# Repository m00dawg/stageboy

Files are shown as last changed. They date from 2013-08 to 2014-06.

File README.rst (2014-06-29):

StageBoy
========

Stage-Hardened ArduinoBoy, Balun, Noise Rejection Box all rolled into one.

Noise-Rejection Explained
-------------------------

The transformer is wired in such a way that the stereo input is wired to the
outside pins of the transformer, with the ground being the center-tap. So left
and right become inversed of each other. Thus, when they are playing the same
content, in theory, the audio would be cancelled out. This is what is being 
exploited to ultimately reject noise.

Hard panning your desired content (e.g. music), say, to the left, and leaving
the right channel with no content means that the noise that is common to both
channels ends up getting rejected by way of being inverted and then cancelled
out.

For the GameBoy, this has a noticeable improvement over the background noise,
including the high pitched whine. Any source which has common noise on both
channels can be used. Which channel is used does not matter, although typically
the left is used as this keep the musical content un-inverted.

In practice, it is not perfect and, in fact, an active circuit (using op-amps)
may further improve rejection. This would have required a much more complicated
power supply and, as a result, the passive route was preffered. It is generally
good when sticking with the recommended transformer (see BOM) or one better. 
The quality of the transformer has a direct affect on both the noise rejection
and the ultiamte quality of the audio output.

Using a transformer means that the output is balanced and isolated. Thus there 
should not be any issues with ground loops and longer audio cables can be used 
with less signal degradation. Most mixers and audio capture devices offer balanced 
inputs and it is highly recommended to use them if at all possible.

Programming the StageBoy
------------------------

Pulling the Chip
~~~~~~~~~~~~~~~~

If you don't want to mess with the ISP headers, you can likely just stuff
an AVR chip which is already Arduinofied (it has the bootlodaer already -
as in you previously flashed it with the bootloader or bought an AVR 
from a place that will flash it for you) into an Uno board and upload
the code as you normally would. Then you can pull the chip and put it into
the StageBoy.

If you're not making any changes, and are reasonably confident with your 
soldering work, this should work without issue. Using the ISP headers, 
however, makes thins easier to troubleshoot.

Using the ISP Headers
~~~~~~~~~~~~~~~~~~~~~

ISP headers have been used successful with EvilMadScientist's ISP Shield
(see http://shop.evilmadscientist.com/productsmenu/tinykitlist/253-ispshield)
and an Arduino Duemilanove. Wires are hooked up in a similar way to the
Arduino ISP how-to (see: http://arduino.cc/en/Tutorial/ArduinoISP) but
with a 6-pin ISP header on the other end. A standard ISP cable should
work, and would be a lot easier, but hasn't been tested.

With the ISP Shield, program the Arduino connect to the shield using the
ArduinoISP sketch available with the Ardunio IDE (under Examples). Then
connect the shield to the Arduino and the ISP cable to the StageBoy. Burning
the bootloader should be optional, but it has never been tested without. To
burn the bootloader, pick the Arduino board you are using as the programmer
in the Tools -> Board menu. Then set the Programmer to Arduino As ISP under
Tools -> Programmer. Then go to Tools -> Burn Bootloader.

Having done that, load up the StageBoy sketch, and then press SHIFT and click
on the upload icon. This uploads the code to the StageBoy instead of to the
Arduino board acting as the programmer.

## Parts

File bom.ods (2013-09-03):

Part | Value | Mouser Part # | Other Part #
Enclosure | .72 x 3.07 x 1.69 Extruded Enclsoure | 546-1455K1201 (https://www.mouser.com/Search/ProductDetail.aspx)
B1 | Rectifier | 625-W005G-E4
C3 | 22pF | 581-SA102A220JAR (http://www.mouser.com/Search/ProductDetail.aspx)
C4 | 22pF | 581-SA102A220JAR (http://www.mouser.com/Search/ProductDetail.aspx)
C1 | 100nF | 810-FK18X7R1E104K (http://www.mouser.com/Search/ProductDetail.aspx)
C2 | 100nF | 810-FK18X7R1E104K (http://www.mouser.com/Search/ProductDetail.aspx)
C5 | 100nF | 810-FK18X7R1E104K (http://www.mouser.com/Search/ProductDetail.aspx)
C9 | 100nF | 810-FK18X7R1E104K (http://www.mouser.com/Search/ProductDetail.aspx)
C8 | 330nF | 810-FK18X5R1E334K
C6 | 22uF | 667-EEU-HD1H220B
C7 | 2200uF | 667-EEU-HD1E222B
D1 | 1N4148 Diode | 512-1N4148 (http://www.mouser.com/ProductDetail/Fairchild-Semiconductor/1N4148/?qs=sGAEpiMZZMudZehw8RjeZWbu6z6oTQTL)
GB5V | 2-pin Jumper |  | avishowtech.com
GNDLFT | 2-pin Jumper |  | avishowtech.com
MIDI-IN | 2-pin SIL Header |  | avishowtech.com
MIDI-OUT | 3-pin SIL Header |  | avishowtech.com
5VDC | 2-pin SIL Header |  | avishowtech.com
X4 | 2-pin SIL Header |  | avishowtech.com
ISP | 2x3 DIL Header |  | avishowtech.com
R5 | 220 Ohm | 660-MF1/4CCT52R2200F (http://www.mouser.com/Search/ProductDetail.aspx)
R9 | 220 Ohm | 660-MF1/4CCT52R2200F (http://www.mouser.com/Search/ProductDetail.aspx)
R10 | 220 Ohm | 660-MF1/4CCT52R2200F (http://www.mouser.com/Search/ProductDetail.aspx)
R8 | 270 Ohm | 660-MF1/4DC2700F (http://www.mouser.com/Search/ProductDetail.aspx)
SW1 | 3-Position DIP | 611-BD03
MIDI IN | Female MIDI |  | avishowtech.com
MIDI OUT | Female MIDI |  | avishowtech.com
GBIO | Female MIDI |  | avishowtech.com
GB Connector | Male 5-pin DIN 180 Deg | 568-NYS322G (http://www.mouser.com/Search/ProductDetail.aspx?R=NYS322Gvirtualkey56810000virtualkey568-NYS322G) | <--- Untested
IC1 | AVR328 | 556-ATMEGA328P-PU (http://www.mouser.com/Search/ProductDetail.aspx)
IC1 Socket | 28-pin Narrow (.3”) | 517-4828-3004-CP (http://www.mouser.com/Search/ProductDetail.aspx)
IC2 | 7805 | 511-L7805CV (http://www.mouser.com/Search/ProductDetail.aspx?R=L7805CVvirtualkey51120000virtualkey511-L7805CV)
OK1 | 6N138 Optocoupler | 782-6N138 (http://www.mouser.com/Search/ProductDetail.aspx?R=6N138virtualkey61370000virtualkey782-6N138)
OK1 Socket | 8-pin DIP Socket | 517-4808-3000-CP (http://www.mouser.com/Search/ProductDetail.aspx)
STEREO IN | 3.5mm Audio Jack | 806-STX-31205B284C (http://www.mouser.com/Search/ProductDetail.aspx)
MONO BALANCED OUT | 1/4” TRS Jack | 550-20301 (https://www.mouser.com/Search/ProductDetail.aspx?R=NMJ6HFD2virtualkey56810000virtualkey550-20301)
J1 | 2mm/5mm DC Jack | 806-KLDX-0202-A (http://www.mouser.com/ProductDetail/Kycon/KLDX-0202-A/)
LED | 3mm LED |  | avishowtech.com
Q1 | 16MHz OSC | 695-HC49US-16-U (http://www.mouser.com/Search/ProductDetail.aspx)
XFORMER | EDCOR PCW |  | edcor.com

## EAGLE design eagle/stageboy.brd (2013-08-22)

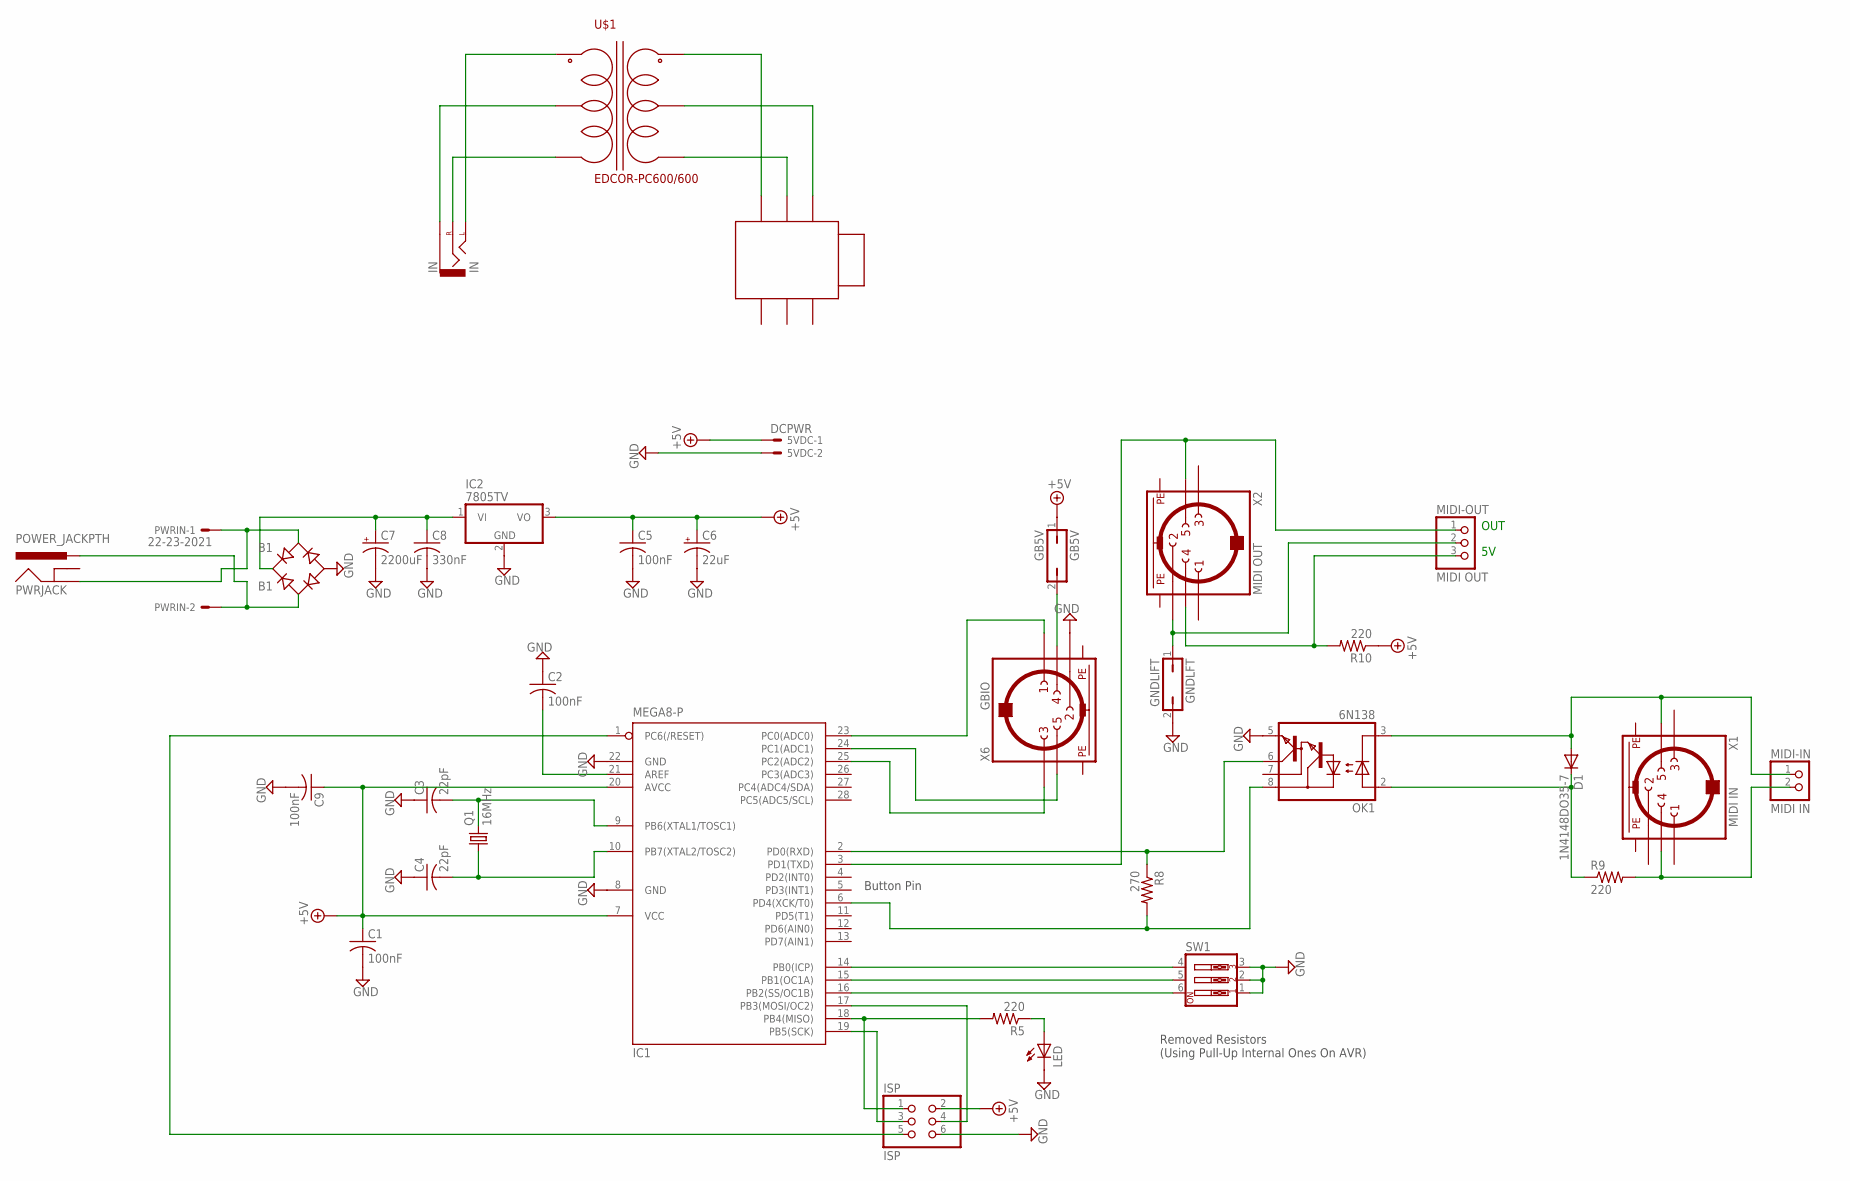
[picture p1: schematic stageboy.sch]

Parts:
5VDC: DCPWR; 22-23-2021
B1: B1; RB1A
C1, C2, C5, C9: 100nF; C025-025X050
C3, C4: 22pF; C025-025X050
C6: 22uF; E2,5-5
C7: 2200uF; E5-13
C8: 330nF; C025-025X050
D1: 1N4148DO35-7; DO35-7
GB5V: GB5V; JP1
GNDLFT: GNDLIFT; JP1
IC1: MEGA8-P; DIL28-3
IC2: 7805TV; TO220V
IN: IN; AUDIO-JACK
ISP: ISP; 2X03
LED: LED3MM
MIDI-IN: MIDI IN; 1X02
MIDI-OUT: MIDI OUT; 1X03
OK1: 6N138; DIL08
OUT: NMJ6HFD2
PWRIN: 22-23-2021
PWRJACK: POWER_JACKPTH; POWER_JACK_PTH
Q1: 16MHz; HC49/S
R5, R9, R10: 220; 0204/7
R8: 270; 0204/7
SW1: SW_DIP-3; EDG-03
U$1: EDCOR-PC600/600; PCW-12PIN
X1: MIDI IN; MAB5SH
X2: MIDI OUT; MAB5SH
X6: GBIO; MAB5SH

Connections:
+5V: 5VDC.1, C1.1, C5.1, C6.+, C9.1, GB5V.1, IC1.7 (VCC), IC1.20 (AVCC), IC2.3 (VO), ISP.2, R10.1
GND: 5VDC.2, B1.-, C1.2, C2.1, C3.1, C4.1, C5.2, C6.-, C7.-, C8.2, C9.2, GNDLFT.2, IC1.8 (GND), IC1.22 (GND), IC2.2 (GND), ISP.6, LED.K (C), OK1.5 (GND), SW1.1, SW1.2, SW1.3, X6.2
unnamed: IC1.1 (PC6(/RESET)), ISP.5
unnamed: C2.2, IC1.21 (AREF)
unnamed: LED.A, R5.1
unnamed: IC1.14 (PB0(ICP)), SW1.4
unnamed: IC1.15 (PB1(OC1A)), SW1.5
unnamed: IC1.16 (PB2(SS/OC1B)), SW1.6
unnamed: IC1.6 (PD4(XCK/T0)), OK1.8 (VCC), R8.2
unnamed: IC1.2 (PD0(RXD)), OK1.6 (VO), R8.1
unnamed: D1.A, MIDI-IN.1, OK1.3 (C), X1.5
unnamed: D1.C, OK1.2 (A), R9.1
unnamed: MIDI-IN.2, R9.2, X1.4
unnamed: IC1.17 (PB3(MOSI/OC2)), ISP.4
unnamed: IC1.18 (PB4(MISO)), ISP.1, R5.2
unnamed: IC1.19 (PB5(SCK)), ISP.3
unnamed: GB5V.2, X6.4
unnamed: IC1.3 (PD1(TXD)), MIDI-OUT.1, X2.5
unnamed: C4.2, IC1.10 (PB7(XTAL2/TOSC2)), Q1.1
unnamed: IC1.25 (PC2(ADC2)), X6.3
unnamed: C3.2, IC1.9 (PB6(XTAL1/TOSC1)), Q1.2
unnamed: IC1.24 (PC1(ADC1)), X6.5
unnamed: IC1.23 (PC0(ADC0)), X6.1
unnamed: MIDI-OUT.3, R10.2, X2.4
unnamed: B1.+, C7.+, C8.1, IC2.1 (VI)
unnamed: IN.TIP (LEFT), U$1.P$1
unnamed: OUT.GND-IN, U$1.P$8
unnamed: OUT.LEFT-IN, U$1.P$7
unnamed: OUT.RIGHT-IN, U$1.P$9
unnamed: IN.SLEEVE, U$1.P$2
unnamed: B1.AC2, PWRIN.1, PWRJACK.GND
unnamed: B1.AC1, PWRIN.2, PWRJACK.PWR
unnamed: IN.RING (RIGHT), U$1.P$3
unnamed: GNDLFT.1, MIDI-OUT.2, X2.2
PE: X1.PE, X1.PE@ (PE), X2.PE, X2.PE@ (PE), X6.PE, X6.PE@ (PE)

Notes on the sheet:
OUT
Button Pin
Removed Resistors (Using Pull-Up Internal Ones On AVR)

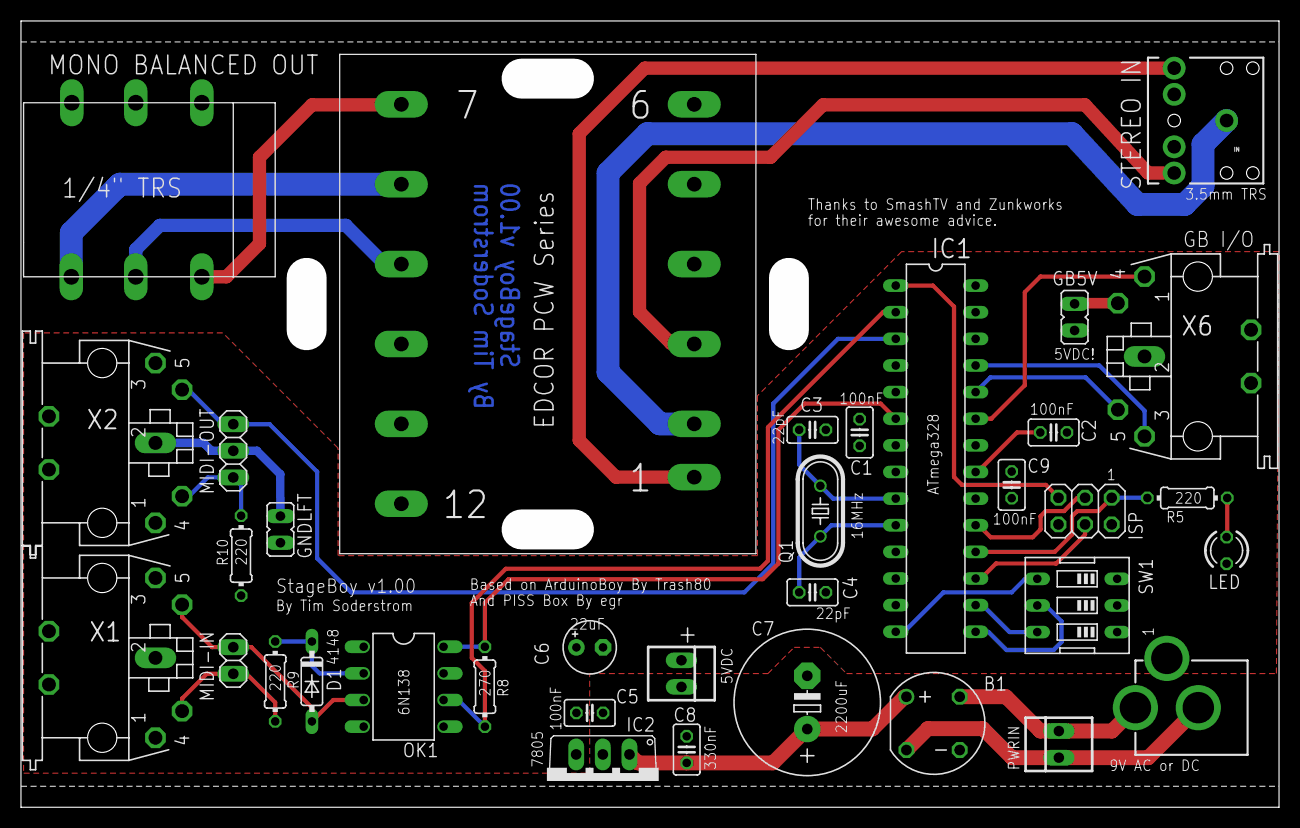
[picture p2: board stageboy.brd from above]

Board: 2 copper layers, 120.0 x 75.0 mm, 35 parts (0 on the bottom side), 35 nets.

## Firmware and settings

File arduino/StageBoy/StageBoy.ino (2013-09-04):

/*
 * StageBoy, An ArduinoBoy Fork
 * Version 1.0.0
 * Based on ArduinoBoy 1.2.3 (http://code.google.com/p/arduinoboy/)
 *
 * Pin Settings:
 *   - DIP Switch On Pins 8-10
 *   - LED on Pin 12
 *   - MIDI Opto-Isolator Power On Pin 4
 *   - GameBoy Clock On Analog Pin 0
 *   - Serial Data To GameBoy On Pin 1
 *   - Serial Data From GameBoy On Pin 2
 
 *                                                                         *
 * Program Information:                                                    *
 *    LSDJ Slave Mode Midi Note Effects:                                   *
 *      48 - C-2 Sends a Sequencer Start Command                           *
 *      49 - C#2 Sends a Sequencer Stop Command                            *
 *      50 - D-2 Toggles Normal Tempo                                      *
 *      51 - D#2 Toggles 1/2 Tempo                                         *
 *      52 - E-2 Toggles 1/4 Tempo                                         *
 *      53 - F-2 Toggles 1/8 Tempo                                         *
 *                                                                         *
 *    LSDJ Keyboard Mode:                                                  *
 *      48 - C-2 Mute Pu1 Off/On                                           *
 *      49 - C#2 Mute Pu2 Off/On                                           *
 *      50 - D-2 Mute Wav Off/On                                           *
 *      51 - D#2 Mute Noi Off/On                                           *
 *      52 - E-2 Livemode Cue Sequence                                     *
 *      53 - F-2 Livemode Cursor Up                                        *
 *      54 - F#2 Livemode Cursor Down                                      *
 *      55 - G-2 Livemode Cursor Left                                      *
 *      56 - G#2 Livemode Cursor Right                                     *
 *      57 - A-2 Table Up                                                  *
 *      58 - A#2 Table Down                                                *
 *      59 - B-2 Cue Table                                                 *
 *      60 - C-3 to C-8 Notes!                                             *
 *      Prgram Change to select from instrument table                      *
 *                                                                         *
 ***************************************************************************/
/***************************************************************************
 *                                                                         *
 *   This program is free software; you can redistribute it and/or modify  *
 *   it under the terms of the GNU General Public License as published by  *
 *   the Free Software Foundation; either version 2 of the License, or     *
 *   (at your option) any later version.                                   *
 *                                                                         *
 ***************************************************************************/
#include <EEPROM.h>
#define MEM_MAX 65
#define NUMBER_OF_MODES 7    //Right now there are 7 modes, Might be more in the future

//!!! do not edit these, they are the position in EEPROM memory that contain the value of each stored setting
#define MEM_CHECK 0
#define MEM_VERSION_FIRST 1
#define MEM_VERSION_SECOND 2
#define MEM_MODE 5
#define MEM_FORCE_MODE 4

#define MEM_LSDJSLAVE_MIDI_CH 6

#define MEM_LSDJMASTER_MIDI_CH 7
#define MEM_KEYBD_CH 8

#define MEM_KEYBD_COMPAT_MODE 9
#define MEM_KEYBD_CH_TO_INST 10

#define MEM_MIDIOUT_NOTE_CH 11
#define MEM_MIDIOUT_CC_CH 15
#define MEM_MIDIOUT_CC_MODE 19
#define MEM_MIDIOUT_CC_SCALING 23
#define MEM_MIDIOUT_CC_NUMBERS 27

#define MEM_MGB_CH 55
#define MEM_LIVEMAP_CH 60

#define MEM_MIDIOUT_BIT_DELAY 61
#define MEM_MIDIOUT_BYTE_DELAY 63



/***************************************************************************
* User Settings
***************************************************************************/

boolean alwaysUseDefaultSettings = false; //set to true to always use the settings below, else they are pulled from memory for the software editor


boolean usbMode                  = false; //to use usb for serial communication as oppose to MIDI - sets baud rate to 38400


byte defaultMemoryMap[MEM_MAX] = {
  0x7F,0x01,0x02,0x7F, //memory init check
  0x00, //force mode (forces lsdj to be sl)
  0x00, //mode
  
  15, //sync effects midi channel (0-15 = 1-16)
  15, //masterNotePositionMidiChannel - LSDJ in master mode will send its song position on the start button via midi note. (0-15 = 1-16)
  
  15, //keyboardInstrumentMidiChannel - midi channel for keyboard instruments in lsdj. (0-15 = 1-16)
  1, //Keyboard Compatability Mode
  1, //Set to true if you want to have midi channel set the instrument number / doesnt do anything anymore
  
  0,1,2,3, //midiOutNoteMessageChannels - midi channels for lsdj midi out note messages Default: channels 1,2,3,4
  0,1,2,3, //midiOutCCMessageChannels - midi channels for lsdj midi out CC messages Default: channels 1,2,3,4
  1,1,1,1, //midiOutCCMode - CC Mode, 0=use 1 midi CC, with the range of 00-6F, 1=uses 7 midi CCs with the
                       //range of 0-F (the command's first digit would be the CC#), either way the value is scaled to 0-127 on output
  1,1,1,1, //midiOutCCScaling - CC Scaling- Setting to 1 scales the CC value range to 0-127 as oppose to lsdj's incomming 00-6F (0-112) or 0-F (0-15) 
  1,2,3,7,10,11,12, //pu1: midiOutCCMessageNumbers - CC numbers for lsdj midi out, if CCMode is 1, all 7 ccs are used per channel at the cost of a limited resolution of 0-F
  1,2,3,7,10,11,12, //pu2
  1,2,3,7,10,11,12, //wav
  1,2,3,7,10,11,12, //noi
  
  0, 1, 2, 3, 4, //mGB midi channels (0-15 = 1-16)
  15, //livemap / sync map midi channel (0-15 = 1-16)
  80,1,  //midiout bit check delay & bit check delay multiplier 
  0,0//midiout byte received delay & byte received delay multiplier 
};
byte memory[MEM_MAX];

/***************************************************************************
* Lets Assign our Arduino Pins .....
***************************************************************************/

int pinGBClock     = 0;    // Analog In 0 - clock out to gameboy
int pinGBSerialOut = 1;    // Analog In 1 - serial data to gameboy
int pinGBSerialIn  = 2;    // Analog In 2 - serial data from gameboy

int pinMidiInputPower = 4; // power pin for midi input opto-isolator
int pinStatusLed = 12; // Status LED

int dipSwitch[] = {8, 9, 10}; // DIP Pins


/***************************************************************************
* Memory
***************************************************************************/

int eepromMemoryByte = 0; //Location of where to store settings from mem



/***************************************************************************
* Sysex Settings & vars
***************************************************************************/

boolean sysexReceiveMode = 0;
boolean sysexProgrammingMode = 0;
boolean sysexProgrammingWaiting = 0;
boolean sysexProgrammingConnected = 0;

unsigned long sysexProgrammerWaitTime = 2000; //2 seconds
unsigned long sysexProgrammerCallTime = 1000; //1 second
unsigned long sysexProgrammerLastResponse = 0;
unsigned long sysexProgrammerLastSent = 0;

byte sysexManufacturerId = 0x69; //har har harrrrr :)
int sysexPosition;
byte sysexData[128];
byte longestSysexMessage = 128;

int midioutBitDelay = 0;
int midioutByteDelay = 0;


/***************************************************************************
* Switches and states
***************************************************************************/
boolean sequencerStarted = false;        //Sequencer has Started
boolean midiSyncEffectsTime = false;
boolean midiNoteOnMode   =false;
boolean midiNoteOffMode  =false;
boolean midiProgramChange=false;
boolean midiAddressMode  =false;
boolean midiValueMode    =false;

int midiOutLastNote[4] = {-1,-1,-1,-1};

boolean statusLedIsOn    =false;
boolean statusLedBlink   =false;

boolean nanoState        =false;
boolean nanoSkipSync     =false;

int buttonDepressed;
int buttonState;
unsigned long int buttonProgrammerWaitTime = 2000; //2 whole seconds
unsigned long int buttonTime;


//boolean blinkSwitch[6];
//unsigned long int blinkSwitchTime[6];
boolean blinkSwitch;
unsigned long int blinkSwitchTime;

int switchLight = 0;

int blinkMaxCount = 1000;

unsigned long midioutNoteTimer[4];
byte midioutNoteHold[4][4];
byte midioutNoteHoldCounter[4];
int midioutNoteTimerThreshold = 10;

byte mode = 0;

/***************************************************************************
* Counter vars
***************************************************************************/
int countLSDJTicks = 0;            //for loop int (we need to cycle 8 pulses)
int countSyncTime  = 0;
int countSyncLightTime=0;
int countSyncSteps = 0;
int countSyncPulse = 0;
int countGbClockTicks =0;
int countClockPause =0;
int countIncommingMidiByte =0;
int countStatusLedOn =0;
unsigned int waitClock =0;


int miscLastLed;
unsigned long int miscLedTime;
unsigned long int miscLedMaxTime;

/***************************************************************************
* Inbound Data Placeholders
***************************************************************************/
byte incomingMidiByte;  //incomming midi message
byte readgbClockLine;
byte readGbSerialIn;
byte bit;
byte midiData[] = {0, 0, 0};
byte lastMidiData[] = {0, 0, 0};

int incomingMidiNote = 0;
int incomingMidiVel = 0;
byte readToggleMode;
byte serialWriteBuffer[256];
byte midiDefaultStartOffset;
int  writePosition=0;
int  readPosition=0;
int lastMode=0; //Stores the last selected mode for leds.

byte midiSyncByte;
byte midiSyncByteLast;

byte midiStatusType;
byte midiStatusChannel;

/***************************************************************************
* LSDJ Keyboard mode settings
***************************************************************************/      
byte keyboardNotes[] = {0x1A,0x1B,0x22,0x23,0x21,0x2A,0x34,0x32,0x33,0x31,0x3B,0x3A,
                         0x15,0x1E,0x1D,0x26,0x24,0x2D,0x2E,0x2C,0x36,0x35,0x3D,0x3C};
byte keyboardOctDn = 0x05;
byte keyboardOctUp = 0x06;

byte keyboardInsDn = 0x04;
byte keyboardInsUp = 0x0C;

byte keyboardTblDn = 0x03;
byte keyboardTblUp = 0x0B;

byte keyboardTblCue= 0x29;

byte keyboardMut1 = 0x01;
byte keyboardMut2 = 0x09;
byte keyboardMut3 = 0x78;
byte keyboardMut4 = 0x07;

byte keyboardCurL = 0x6B;
byte keyboardCurR = 0x74;
byte keyboardCurU = 0x75;
byte keyboardCurD = 0x72;
byte keyboardPgUp = 0x7D;
byte keyboardPgDn = 0x7A;
byte keyboardEntr = 0x5A;

int keyboardCurrentOct = 0;
int keyboardCurrentIns = 0;
int keyboardCurrentTbl = 0;

int keyboardLastOct = 0;
int keyboardLastIns = 0;
int keyboardLastTbl = 0;

int keyboardDiff = 0;
int keyboardCount = 0;
byte keyboardStartOctave = 0x24;
byte keyboardNoteStart = 0;
byte keyboardNoteOffset = 0;
byte keyboardCommands[12];

void setup() {
/*
  Init Memory
*/
  initMemory(0);
/*
  Init Pins
*/
  pinMode(pinStatusLed, OUTPUT);     

  // Setup DIP switches
  for(byte count = 0; count < 3; ++count)
  {
    pinMode(dipSwitch[count], INPUT);
    digitalWrite(dipSwitch[count], HIGH);
  }
  

  DDRC = B00111111; //Set analog in pins as outputs
  
/*
  Set MIDI Serial Rate
*/
  if(usbMode == true) {
    Serial.begin(38400); //31250
  } else {
    pinMode(pinMidiInputPower,OUTPUT); 
    digitalWrite(pinMidiInputPower,HIGH); // turn on the optoisolator
    Serial.begin(31250); //31250
  }
/*
  Set Pin States
*/
  digitalWrite(pinGBClock,HIGH);    // gameboy wants a HIGH line
  digitalWrite(pinGBSerialOut,LOW);    // no data to send
/*
  Misc Startup
*/
  keyboardNoteStart = keyboardStartOctave + 12; // Set the octave where the actual notes start (the octave below is for the mutes, cursor, etc)
/*
  Assign the keyboard mode command array for the first octave
*/
  keyboardCommands[0] = keyboardMut1;
  keyboardCommands[1] = keyboardMut2;
  keyboardCommands[2] = keyboardMut3;
  keyboardCommands[3] = keyboardMut4;
  keyboardCommands[4] = keyboardCurL;
  keyboardCommands[5] = keyboardCurR;
  keyboardCommands[6] = keyboardCurU;
  keyboardCommands[7] = keyboardCurD;
  keyboardCommands[8] = keyboardEntr;
  keyboardCommands[9] = keyboardTblDn;
  keyboardCommands[10] = keyboardTblUp;
  keyboardCommands[11] = keyboardTblCue;
/*
  Load Settings from EEPROM
*/
//  if(!memory[MEM_FORCE_MODE]) memory[MEM_MODE] = EEPROM.read(MEM_MODE);
//  lastMode = memory[MEM_MODE];
  
  
  //showSelectedMode(); //Light up the LED that shows which mode we are in.
  
  //setMode();
  startupSequence();
  delay(1000);

  mode = 0;
  switchMode();
}


/*
  Main Loop, which we don't use to be able to isolate each mode into its own setup and loop functions
*/
void loop () {
  //setMode();
  //switchMode();
}

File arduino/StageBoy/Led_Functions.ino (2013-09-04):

 /*
   showSelectedMode1 turns off the last mode led, turns on the new mode led
   and delays for a period of time to reduce jitter behavior from the mode 
   changing too fast.
 */
void showSelectedMode()
{
  /*
  digitalWrite(pinStatusLed,LOW);
  
  for(int m=0;m<3;m++) {
    switch(memory[MEM_MODE]) {
      case 0:
      case 1:
      case 2:
      case 3:
      case 4:
        digitalWrite(pinLeds[memory[MEM_MODE]],HIGH);
        break;
      case 5:
        digitalWrite(pinStatusLed,HIGH);
        digitalWrite(pinLeds[0],HIGH);
        digitalWrite(pinLeds[1],HIGH);
        break;
      case 6:
        digitalWrite(pinStatusLed,HIGH);
        digitalWrite(pinLeds[0],HIGH);
        digitalWrite(pinLeds[1],HIGH);
        digitalWrite(pinLeds[2],HIGH);
        digitalWrite(pinLeds[3],HIGH);
        digitalWrite(pinLeds[4],HIGH);
        break;
      
    }
  delay(100);
  digitalWrite(pinStatusLed,LOW);
  digitalWrite(pinLeds[0],LOW);
  digitalWrite(pinLeds[1],LOW);
  digitalWrite(pinLeds[2],LOW);
  digitalWrite(pinLeds[3],LOW);
  digitalWrite(pinLeds[4],LOW);
  delay(100);
  }
  lastMode = memory[MEM_MODE];
  delay(300);
  */
}

void updateVisualSync()
{
    if(!countSyncTime) {
      if(!blinkSwitch) digitalWrite(pinStatusLed,HIGH);
      blinkSwitch=1;
      blinkSwitchTime=0;
      countSyncLightTime = 0;
    }
    countSyncTime++;
    if(countSyncTime == 24) countSyncTime=0; 
}



void updateBlinkLights()
{
  updateBlinkLight();
}

void updateBlinkLight()
{
  if(blinkSwitch) {
    blinkSwitchTime++;
    if(blinkSwitchTime == blinkMaxCount) {
      blinkSwitch=0;
      blinkSwitchTime=0;
      digitalWrite(pinStatusLed,HIGH);
    }
  }
}

void updateStatusLight()
{
  if(blinkSwitch) {
    blinkSwitchTime++;
    if(blinkSwitchTime == blinkMaxCount) {
      blinkSwitch=0;
      blinkSwitchTime=0;
      digitalWrite(pinStatusLed,LOW);
    }
  }
}

void blinkLight(byte midiMessage, byte midiValue)
{
  /*
  if(midiValue) {
  switch(midiMessage) {
    case 0x90:
      if(!blinkSwitch[0]) digitalWrite(pinLeds[0],HIGH);
      blinkSwitch[0]=1;
      blinkSwitchTime[0]=0;
      break;
    case 0x91:
      if(!blinkSwitch[1]) digitalWrite(pinLeds[1],HIGH);
      blinkSwitch[1]=1;
      blinkSwitchTime[1]=0;
      break;
    case 0x92:
      if(!blinkSwitch[2]) digitalWrite(pinLeds[2],HIGH);
      blinkSwitch[2]=1;
      blinkSwitchTime[2]=0;
      break;
    case 0x93:
      if(!blinkSwitch[3]) digitalWrite(pinLeds[3],HIGH);
      blinkSwitch[3]=1;
      blinkSwitchTime[3]=0;
      break;
    case 0x94:
      if(!blinkSwitch[0])  digitalWrite(pinLeds[0],HIGH);
      blinkSwitch[0]=1;
      blinkSwitchTime[0]=0;
      if(!blinkSwitch[1]) digitalWrite(pinLeds[1],HIGH);
      blinkSwitch[1]=1;
      blinkSwitchTime[1]=0;
      if(!blinkSwitch[2]) digitalWrite(pinLeds[2],HIGH);
      blinkSwitch[2]=1;
      blinkSwitchTime[2]=0;
      break;
  }
  }
  */
  switch(midiMessage) {
    case 0xE0:
    case 0xE1:
    case 0xE2:
    case 0xE3:
    case 0xE4:
    case 0xB0:
    case 0xB1:
    case 0xB2:
    case 0xB3:
    case 0xB4:
      if(!blinkSwitch) digitalWrite(pinStatusLed,HIGH);
      blinkSwitch=1;
      blinkSwitchTime=0;
      break;
    default:
      break;
  }
}

void updateProgrammerLeds()
{
  if(miscLedTime == miscLedMaxTime) {
    if(sysexProgrammingConnected) {
      miscLedMaxTime = 400;
      //blinkSelectedLight(miscLastLed);
      miscLastLed++;
      if(miscLastLed == 5) miscLastLed = 0;
    } else {
      //blinkSelectedLight(5);
      miscLedMaxTime = 3000;
    }
    miscLedTime=0;
  }
  miscLedTime++;
  updateBlinkLights();
}
 /*
   updateStatusLed should be placed inside of the main loop cycle of a mode function. It counts to a 
   certain number to delay the action of turning off the status led, so the blink is visible to the human eye. ;)> 
   I guess this could be called the blinking routine. 
 */
void updateStatusLed()
{
  if(statusLedIsOn) {                  //is the led on?
    countStatusLedOn++;                //then increment the counter by 1
    if(countStatusLedOn > 3000) {      //if the counter is pretty high
      countStatusLedOn = 0;            //then reset it to zero.
       digitalWrite(pinStatusLed,LOW); //and turn off the status led
       statusLedIsOn  = false;         //and set our "is it on?" to false, cause its off now. ;p
       
    } else if (statusLedBlink && countStatusLedOn == 1) {  //someone told me to blink, because i was already on
       digitalWrite(pinStatusLed,LOW);                     //so I'll turn off and turn back on later..
       
    } else if (statusLedBlink && countStatusLedOn > 1000) {//Now that I've waited long enough I'll finish my blink.
       statusLedBlink = false;                             //Turn off the issued blink
       digitalWrite(pinStatusLed,HIGH);                    //... and finally turn back on.
    }
  }
}

 /*
   statusLedOn is the function to call when we want the status led to blink for us.
   all it does is check if its been already asked to turn on, if it has it will set a flag
   to make it blink. Either way it will reset the blink timer and turn on the LED
 */
void statusLedOn()
{
  if(statusLedIsOn) {
    statusLedBlink = true;   //Make it blink even though its already on
  }
  statusLedIsOn  = true;     //This is the flag the updator function looks for to know if its ok to increment the timer and wait to turn off the led
  countStatusLedOn = 0;      //Reset the timer
  digitalWrite(pinStatusLed,HIGH); //Turn on the led
}

/* cute startup sequence */
/*
void startupSequence()
{
  int ledFxA;
  int ledFxB;
  
  for(ledFxB=0;ledFxB<2;ledFxB++) {
  for(ledFxA=0;ledFxA<6;ledFxA++) {
    digitalWrite(pinLeds[ledFxA], HIGH);
    delay(25);
    digitalWrite(pinLeds[ledFxA], LOW);
  }
  for(ledFxA=4;ledFxA>=0;ledFxA--) {
    digitalWrite(pinLeds[ledFxA], HIGH);
    delay(25);
    digitalWrite(pinLeds[ledFxA], LOW);
  }
  }
  delay(50);
  
  for(ledFxA=0;ledFxA<6;ledFxA++) digitalWrite(pinLeds[ledFxA], HIGH);   // sets the LED on
  delay(100);
  for(ledFxA=0;ledFxA<6;ledFxA++) digitalWrite(pinLeds[ledFxA], LOW);      // sets the digital pin as output
  delay(100);
  for(ledFxA=0;ledFxA<6;ledFxA++) digitalWrite(pinLeds[ledFxA], HIGH);   // sets the LED on
  delay(100);
  for(ledFxA=0;ledFxA<6;ledFxA++) digitalWrite(pinLeds[ledFxA], LOW);      // sets the digital pin as output
  delay(500);
}
*/

void startupSequence()
{
  blinkTimes(5);
}

void blinkTimes(byte num)
{
  for(byte count = 0; count < num; ++count)
  {
    digitalWrite(pinStatusLed,HIGH);
    delay(250);
    digitalWrite(pinStatusLed,LOW);
    delay(250);
  }
}

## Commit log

2013-08-11 Added EagleCAD layouts
    [stageboy-edcor-dips.brd, stageboy-edcor-dips.sch]
2013-08-11 Imported ArduinoBoy v1.2.3
    Also began disabling routines that are no longer needed
    due to the change to using DIP switches over button/LEDs
    [Led_Functions.ino, Mode.ino, Mode_LSDJ_SlaveSync.ino]
2013-08-12 Layout Optimizations
    Moved the TRS jack towards the edge more.
    Adjusted positions on audio-in, GB in, and LEDs.
    [stageboy-edcor-dips.brd]
2013-08-12 Added 5VDC Header
    [stageboy-edcor-dips.brd, stageboy-edcor-dips.sch]
2013-08-16 Added side panels, minor layout changes to board
    [stageboy-edcor-dips.brd, stageboy-edcor-dips.sch]
2013-08-16 Added silkscreen and made minor formatting changes
    [stageboy-edcor-dips.brd, stageboy-edcor-dips.sch]
2013-08-17 Updated panels, board layout
    Updated panels and boards to match each other and make sure things look
    decent. Also formatting things for OshPark.
    [stageboy-edcor-dips.brd]
2013-08-19 Swapped out DC jack
    Swapped DC jack out for one that uses large vias, as OshPark
    doesn't do plated cutouts. Looks like most any DC jack will do,
    but the part swapped was one from the SparkFun library.
    [stageboy-edcor-dips.brd, stageboy-edcor-dips.sch]
2013-08-19 Moved I/O components to the edges
    [stageboy-edcor-dips.brd]
2013-08-19 Added an alternate board layout
    This layout moves the AVR down further away from the analog
    bits and expands the ground and power planes, while also
    replacing the pull-down resistors with the internal AVR
    pull-ups.
    [stageboy-edcor-dips-alt1.brd, stageboy-edcor-dips-alt1.sch]
2013-08-19 Routing optimizations
    Made some routing optimizations in the analog section.
    Bigger traces and more direct routing.
    [stageboy-edcor-dips-alt1.brd]
2013-08-19 Added holes for zip-ties
    Added holes to run zipties through for the tranny.
    Thought I already added these?
    [stageboy-edcor-dips-alt1.brd]
2013-08-19 Fixed slant in power plane
    [stageboy-edcor-dips-alt1.brd]
2013-08-20 Layout Changes
    Extended PWR/GND planes
    Moved the DIP switch around
    Push the DC jack inwards to be flush-mounted to PCB
    Other minor routing changes
    [stageboy-edcor-dips-alt1.brd]
2013-08-20 Routing optimizations, Zip-Tie holes
    Numerous routing changes / optimizations were made to help make the
    best use of the ground and power planes for both power/gnd delivery
    as well as isolation. On that note, the isolation on both planes
    was lowered to 12 mil.
    Added two more zip-tie holes. The cuts were not showing up on
    the OshPark previews so I switched to using a line, which does show
    up. Not enitrely show how well they exactly they will come out,
    but I think the clearance is enough.
    [stageboy-edcor-dips-alt1.brd, stageboy-edcor-dips-alt1.sch]
2013-08-20 Rouge via...
    [stageboy-edcor-dips-alt1.brd]
2013-08-22 Picked a board layout and named it accordingly
    [stageboy-edcor-dips-alt1.brd, stageboy-edcor-dips.sch, stageboy.brd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]
2013-08-22 Resized the electrolytic capacitors
    The 2200uF cap was way too small, with the 22uF being only slightly
    so. Both were changed and components shifted around as needed.
    [stageboy.brd, stageboy.sch]
2013-08-22 Minor routing change
    [stageboy.brd]
2013-08-22 Moved the DIP switch around a bit
    [stageboy.brd]
2013-08-22 Added Bill of Materials
    [bom.ods, stageboy.brd, stageboy.sch]
2013-08-22 More minor routing changes
    [stageboy.brd]
2013-08-22 MIDI-IN header was a bit tight
    [stageboy.brd]
2013-09-03 Modified StageBoy Switch/LED Behavior
    Commented-out and modified the old functions for handling the
    LEDs and button and replaced them with a simple function to
    read the DIP switch and, if it's different from the current
    mode, switch to that mode.
    [bom.ods]
2014-06-29 Updated README with ISP information
    Updated the README with a quick and dirty howto on how to program an
    AVR while housed inside the StageBoy using ISP headers and an Arduino
    as an ISP programmer.
2014-06-29 Added an explanation about the audio circuit

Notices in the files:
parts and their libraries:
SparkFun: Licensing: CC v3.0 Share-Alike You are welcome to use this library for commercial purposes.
